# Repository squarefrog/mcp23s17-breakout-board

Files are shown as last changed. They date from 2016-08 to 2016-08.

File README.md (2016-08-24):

# MCP23S17 Breakout Board



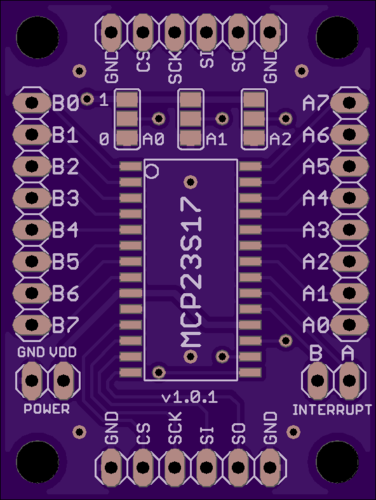
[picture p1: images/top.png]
Board front Board top

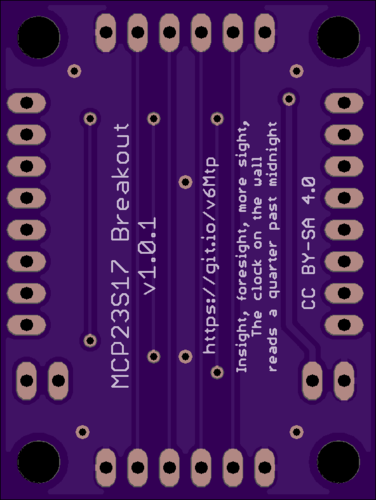
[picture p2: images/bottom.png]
Board back Board bottom


A 30x40mm breakout board for the [MCP23S17](http://www.microchip.com/wwwproducts/en/MCP23S17) SOIC package.

As used in my [MIDI Encoder Box](https://github.com/squarefrog/teensy-midi-encoder-box) project.

## Assembly

1. Start by soldering the MCP23S17 chip onto the board. Ensure you note the position of pin 1 by looking for the dot on the board and the chip.

2. **NOTE:** before proceeding any further, consider what you'd like the hardware address of the chip to be. There are 3 solder jumpers at the top of the board. You may use these to assign an address to the chip. Connect the middle pin of `A0`, `A1`, `A2`, to either ground (labelled `0`), or VDD (labelled `1`). Simply use some solder to join the two pads together.

3. Next, solder on the 2 1x8 header pins. Solder one edge pin first, then check that the header is straight. Once you're happy the header is straight solder the rest of the pins.

4. Now do the same for the 2 1x2 interrupt and power pins.

5. Finally, solder the 2 1x4 SPI header pins in place. Optionally, you may want to use 1x6 headers and get an extra few ground connections.

## IMPORTANT

Ensure you don't forget to solder the jumper pads. Even if you don't plan to use hardware addressing, you should bridge between the middle pin and ground pin.

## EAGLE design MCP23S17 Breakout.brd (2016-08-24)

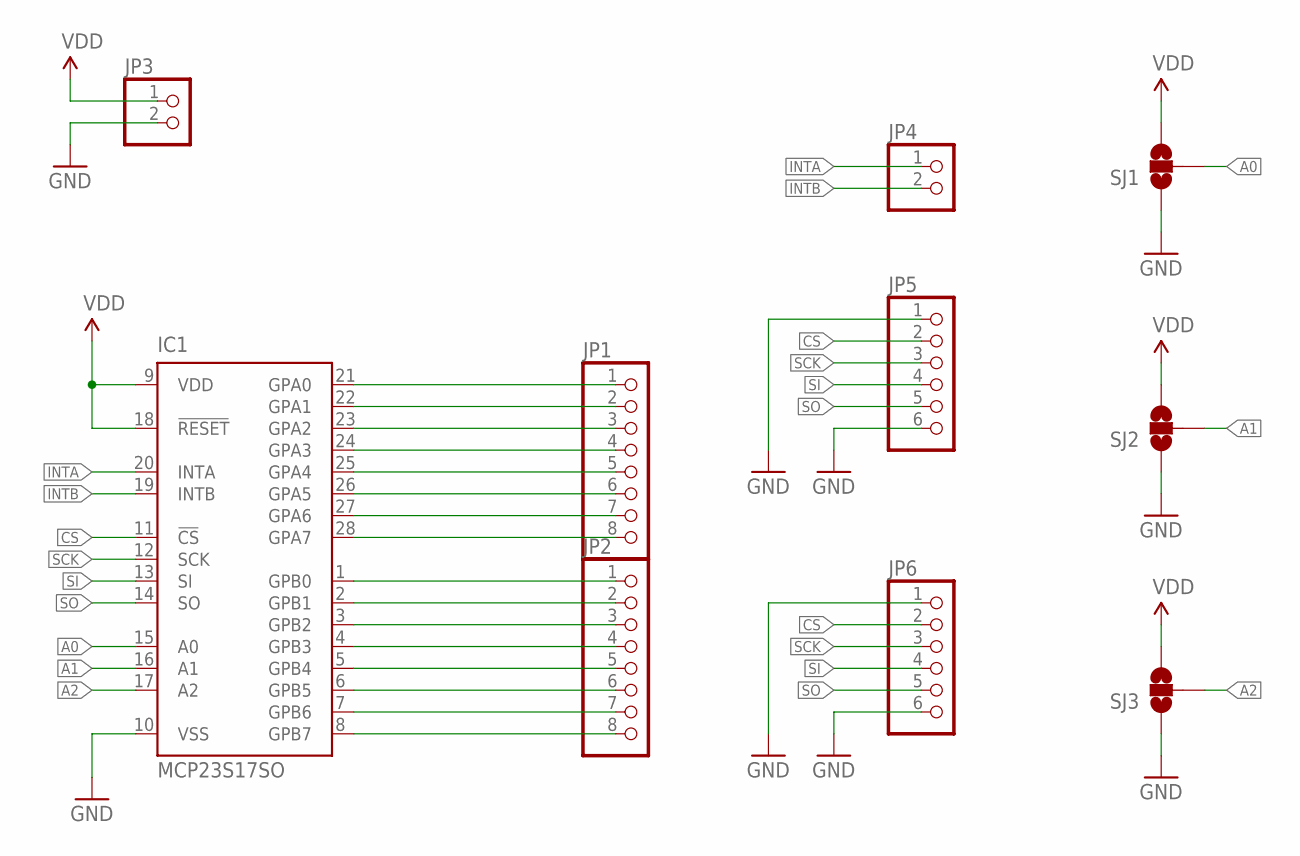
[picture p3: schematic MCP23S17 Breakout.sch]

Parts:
IC1: MCP23S17SO; SO28W
JP1, JP2: PINHD-1X8; 1X08
JP3, JP4: PINHD-1X2; 1X02
JP5, JP6: PINHD-1X6; 1X06
SJ1, SJ2, SJ3: SOLDERJUMPER_2WAYT; SJ_2

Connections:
3.3V: IC1.9 (VDD), IC1.18 (!RESET), JP3.1, SJ1.3, SJ2.3, SJ3.3
A0: IC1.15 (A0), SJ1.2
A1: IC1.16 (A1), SJ2.2
A2: IC1.17 (A2), SJ3.2
CS: IC1.11 (!CS), JP5.2, JP6.2
GND: IC1.10 (VSS), JP3.2, JP5.1, JP5.6, JP6.1, JP6.6, SJ1.1, SJ2.1, SJ3.1
INTA: IC1.20 (INTA), JP4.1
INTB: IC1.19 (INTB), JP4.2
unnamed: IC1.21 (GPA0), JP1.1
unnamed: IC1.22 (GPA1), JP1.2
unnamed: IC1.23 (GPA2), JP1.3
unnamed: IC1.24 (GPA3), JP1.4
unnamed: IC1.25 (GPA4), JP1.5
unnamed: IC1.26 (GPA5), JP1.6
unnamed: IC1.27 (GPA6), JP1.7
unnamed: IC1.28 (GPA7), JP1.8
unnamed: IC1.1 (GPB0), JP2.1
unnamed: IC1.2 (GPB1), JP2.2
unnamed: IC1.3 (GPB2), JP2.3
unnamed: IC1.4 (GPB3), JP2.4
unnamed: IC1.5 (GPB4), JP2.5
unnamed: IC1.6 (GPB5), JP2.6
unnamed: IC1.7 (GPB6), JP2.7
unnamed: IC1.8 (GPB7), JP2.8
SCK: IC1.12 (SCK), JP5.3, JP6.3
SI: IC1.13 (SI), JP5.4, JP6.4
SO: IC1.14 (SO), JP5.5, JP6.5

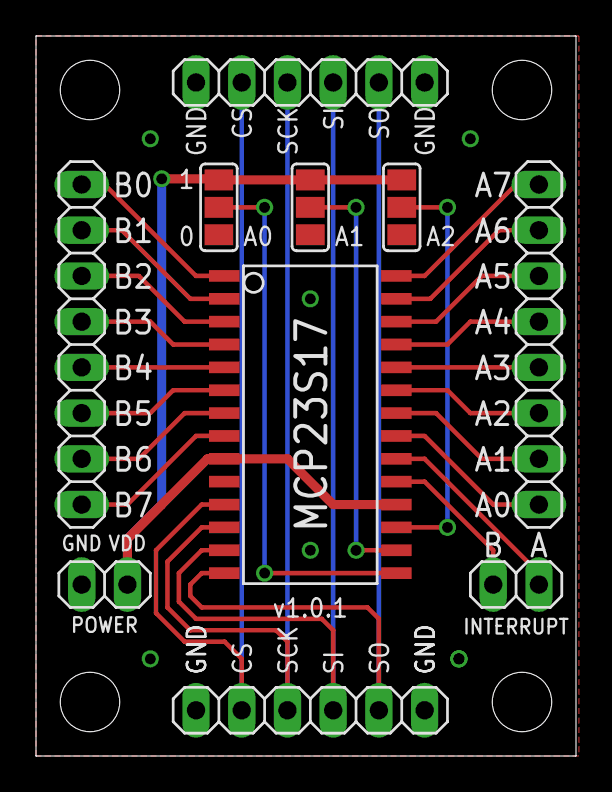
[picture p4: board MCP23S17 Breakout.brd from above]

Board: 2 copper layers, 30.0 x 40.0 mm, 14 parts (0 on the bottom side), 27 nets.

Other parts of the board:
U$1, U$2, U$3, U$4: STAND-OFF

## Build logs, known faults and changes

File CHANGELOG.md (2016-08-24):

# MCP23S17 Breakout Board Changelog

## 1.0.1

- Added spare GND pins
- Added quote to back
- Renumber schematic
- Cleanup schematic
- Check font size/width to ensure lines are over 5mil

## 1.0.0

- Initial release

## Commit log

2016-08-20 Add assembly instructions.
2016-08-24 Update breakout
    [MCP23S17 Breakout.brd, MCP23S17 Breakout.sch]
2016-08-24 Update font sizes
    [MCP23S17 Breakout.brd]

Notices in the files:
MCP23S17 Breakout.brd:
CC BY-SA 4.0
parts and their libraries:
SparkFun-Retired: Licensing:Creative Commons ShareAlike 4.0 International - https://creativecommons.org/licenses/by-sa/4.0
